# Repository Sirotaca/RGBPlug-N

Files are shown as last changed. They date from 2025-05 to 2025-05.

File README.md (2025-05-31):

# RGBPlug Type N
Compact DE-15 ("VGA") adapter for the SNES/SFC-style AV multi-out. Video timing is unchanged, so a monitor or video processor compatible with 15 kHz RGB is required. The switch toggles between separate H/V sync or composite sync output.

For the NTSC SNES/SFC or PAL GameCube, populate C6-C11 but do not populate R6-R8. For the PAL SNES, populate R6-R8 and bridge the pads of C6-C11.

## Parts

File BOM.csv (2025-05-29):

Reference | Value | Datasheet | Footprint | Qty | DNP
C1 | 1nF | ~ | Capacitor_SMD:C_0805_2012Metric_Pad1.18x1.45mm_HandSolder | 1
C2 | 0.01uF | ~ | Capacitor_SMD:C_0805_2012Metric_Pad1.18x1.45mm_HandSolder | 1
C3 | 10uF | ~ | Capacitor_SMD:C_1206_3216Metric_Pad1.33x1.80mm_HandSolder | 1
C4 | 0.1u | ~ | Capacitor_SMD:C_0805_2012Metric_Pad1.18x1.45mm_HandSolder | 1
C5 | 0.1uF | ~ | Capacitor_SMD:C_0805_2012Metric_Pad1.18x1.45mm_HandSolder | 1
C6,C7,C8 | 0.01u | ~ | Capacitor_SMD:C_0805_2012Metric_Pad1.18x1.45mm_HandSolder | 3
C9,C10,C11 | 470u | ~ | Capacitor_THT:CP_Radial_D6.3mm_P2.50mm | 3
J1 | DB15_Female_HighDensity_MountingHoles | ~ | retro_gaming:L17HTHES4F1C | 1
J2 | AudioJack3 | ~ | Connector_Audio:Jack_3.5mm_CUI_SJ1-3533NG_Horizontal | 1
P1 | SNES_multiAV_plug_PCB |  | retro_gaming:SNES_multiAV_plug_PCB | 1
R1,R2,R6,R7,R8 | 75 | ~ | Resistor_SMD:R_0805_2012Metric_Pad1.20x1.40mm_HandSolder | 5
R3 | 10k | ~ | Resistor_SMD:R_0805_2012Metric_Pad1.20x1.40mm_HandSolder | 1
R4,R5 | 510 | ~ | Resistor_SMD:R_0805_2012Metric_Pad1.20x1.40mm_HandSolder | 2
S1 | JS202011CQN | https://www.ckswitches.com/media/1422/js.pdf | Button_Switch_THT:SW_CuK_JS202011CQN_DPDT_Straight | 1
U1 | LMH1980 | LMH1980 | Package_SO:VSSOP-10_3x3mm_P0.5mm | 1
U2 | 74LVC3G34 | http://www.ti.com/lit/sg/scyt129e/scyt129e.pdf | Package_SO:TSSOP-8_3x3mm_P0.65mm | 1

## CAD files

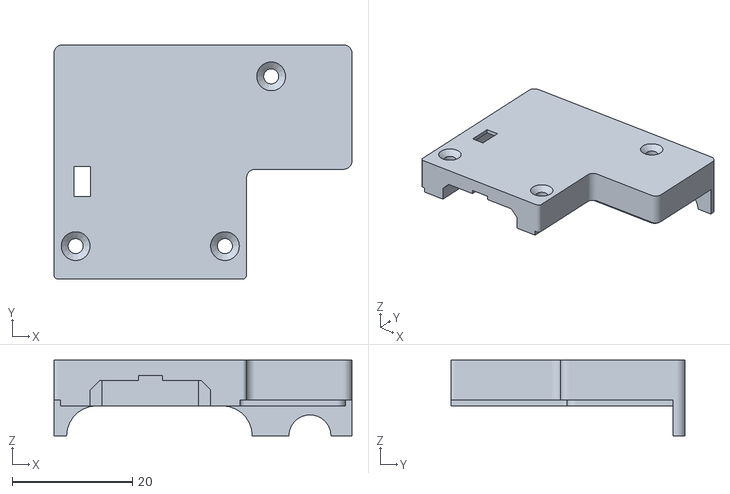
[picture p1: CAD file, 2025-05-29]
Shell/rgbplug_n_top.stl
49.5 x 39.0 x 12.6

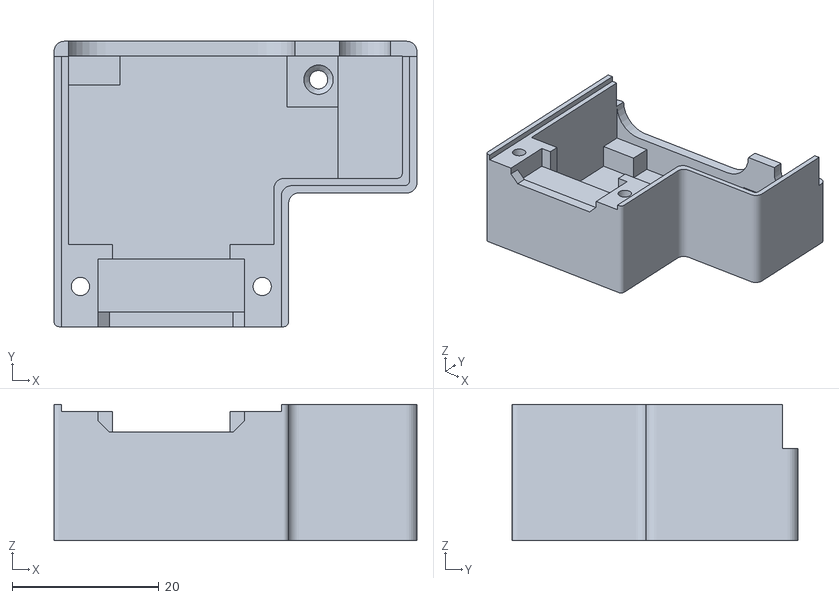
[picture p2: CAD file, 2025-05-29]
Shell/rgbplug_n_bottom.stl
49.5 x 39.0 x 18.6

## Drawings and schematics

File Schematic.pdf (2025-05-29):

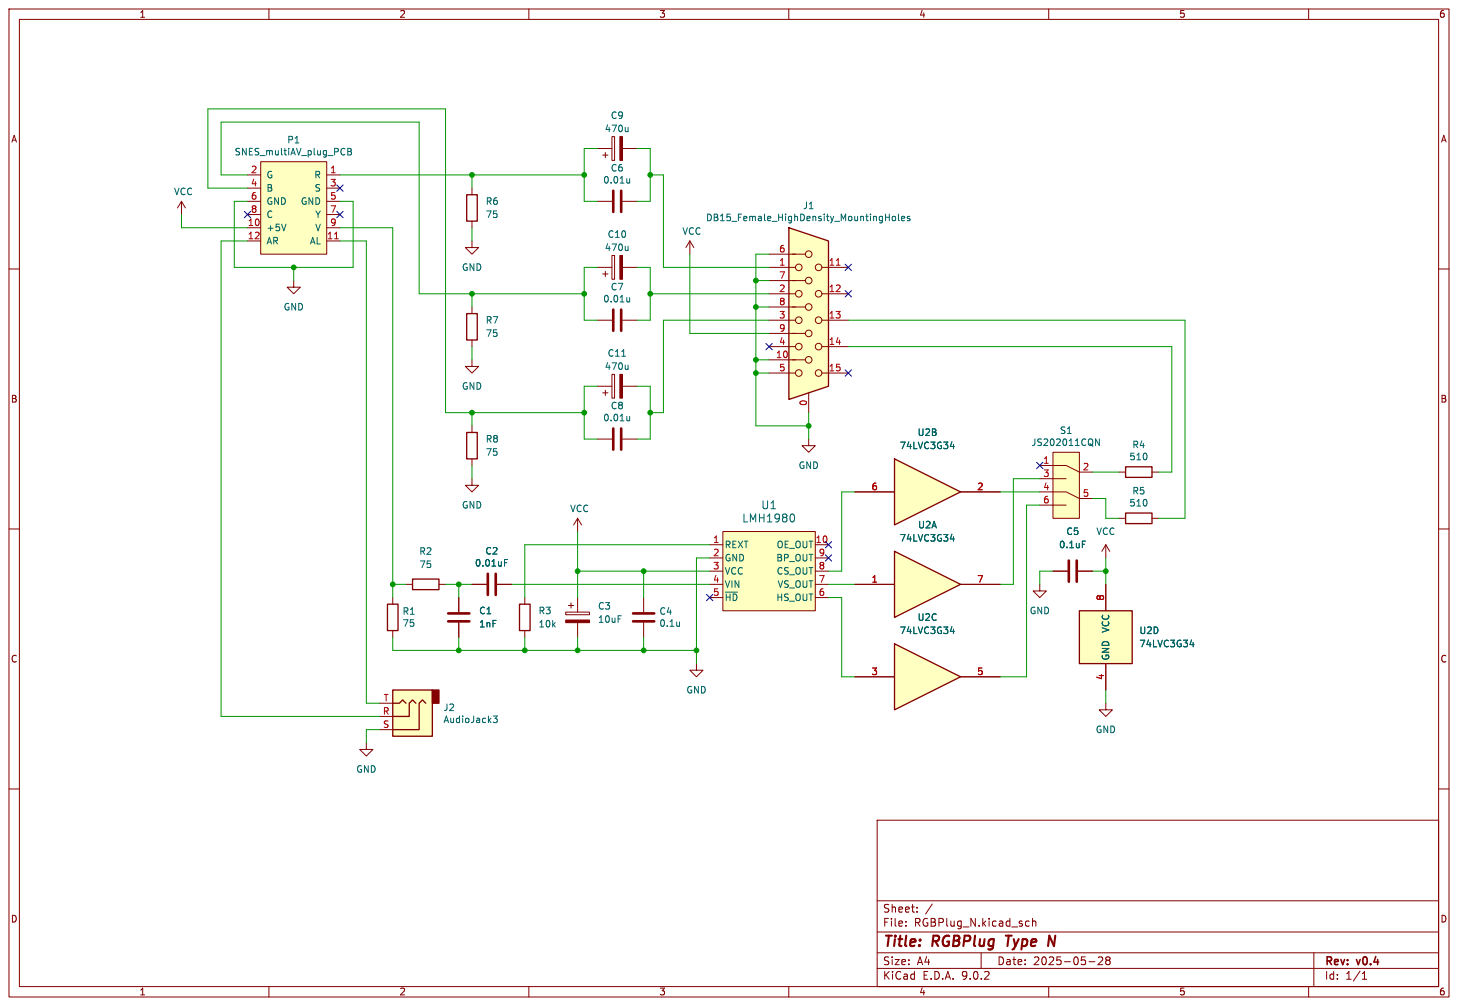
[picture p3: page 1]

Id: 1/1 Title: RGBPlug Type N

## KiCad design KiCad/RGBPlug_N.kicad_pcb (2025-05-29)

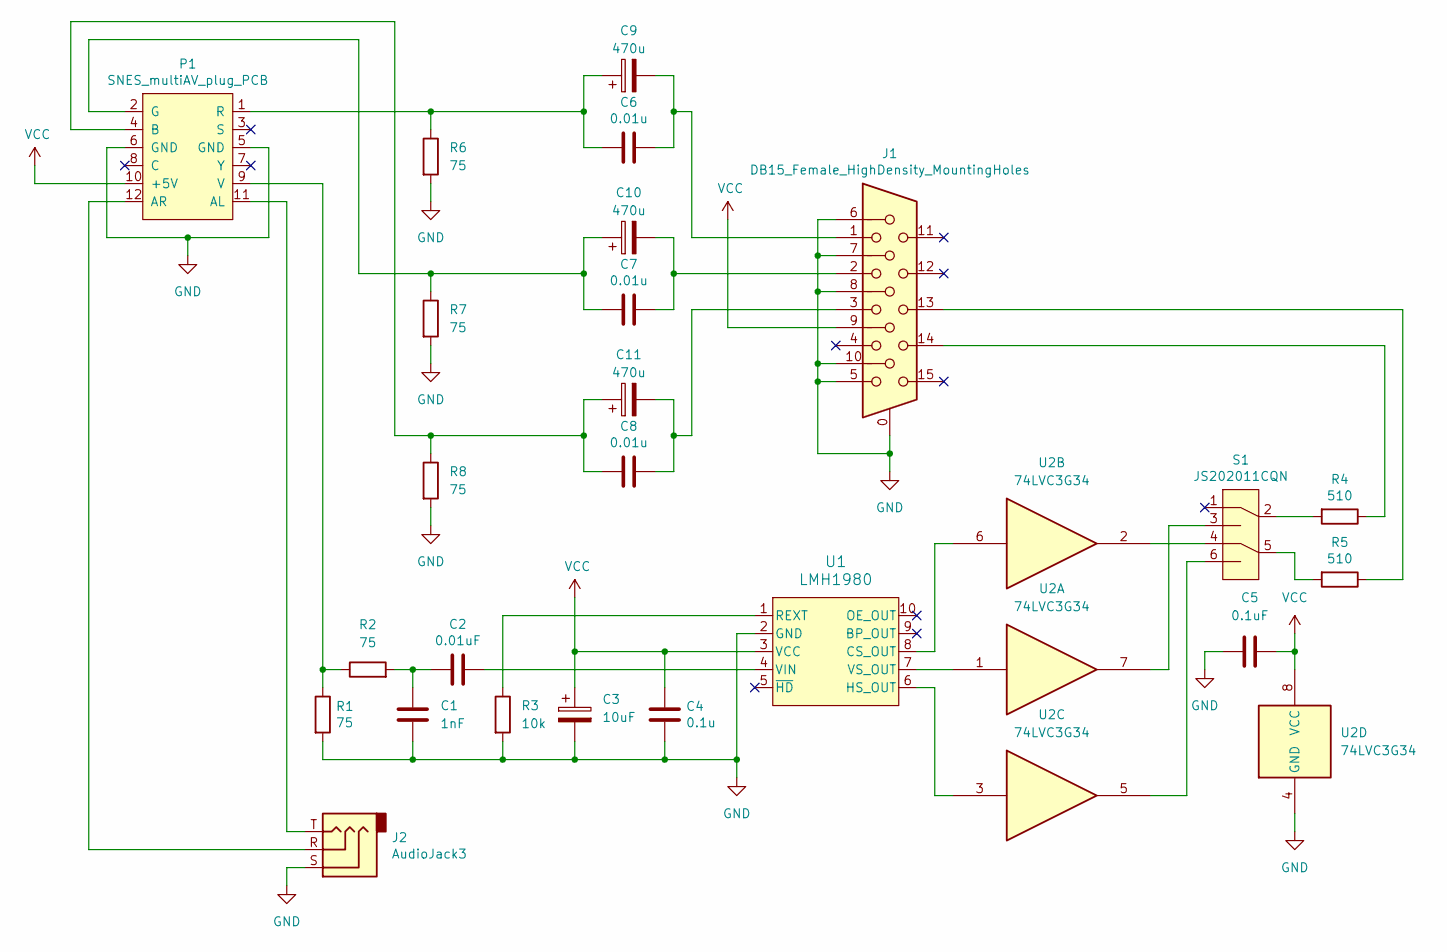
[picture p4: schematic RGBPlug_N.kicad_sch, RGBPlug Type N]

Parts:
C1: 1nF; C_0805_2012Metric_Pad1.18x1.45mm_HandSolder
C2: 0.01uF; C_0805_2012Metric_Pad1.18x1.45mm_HandSolder
C3: 10uF; C_1206_3216Metric_Pad1.33x1.80mm_HandSolder
C4: 0.1u; C_0805_2012Metric_Pad1.18x1.45mm_HandSolder
C5: 0.1uF; C_0805_2012Metric_Pad1.18x1.45mm_HandSolder
C6, C7, C8: 0.01u; C_0805_2012Metric_Pad1.18x1.45mm_HandSolder
C9, C10, C11: 470u; CP_Radial_D6.3mm_P2.50mm
J1: DB15_Female_HighDensity_MountingHoles; L17HTHES4F1C
J2: AudioJack3; Jack_3.5mm_CUI_SJ1-3533NG_Horizontal
P1: SNES_multiAV_plug_PCB
R1, R2, R6, R7, R8: 75; R_0805_2012Metric_Pad1.20x1.40mm_HandSolder
R3: 10k; R_0805_2012Metric_Pad1.20x1.40mm_HandSolder
R4, R5: 510; R_0805_2012Metric_Pad1.20x1.40mm_HandSolder
S1: JS202011CQN; SW_CuK_JS202011CQN_DPDT_Straight
U1: LMH1980; VSSOP-10_3x3mm_P0.5mm
U2: 74LVC3G34; TSSOP-8_3x3mm_P0.65mm

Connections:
GND: C1.2, C3.2, C4.1, C5.1, J1.0, J1.5, J1.6, J1.7, J1.8, J1.10, J2.S, P1.5 (GND), P1.6 (GND), R1.2, R3.2, R6.2, R7.2, R8.2, U1.2 (GND), U2.4 (GND)
unnamed: C1.1, C2.2, R2.2
unnamed: C6.1, C9.2, J1.1
unnamed: C7.1, C10.2, J1.2
unnamed: C8.2, C11.2, J1.3
unnamed: J1.13, R5.1
unnamed: J1.14, R4.1
unnamed: J2.T, P1.11 (AL)
unnamed: J2.R, P1.12 (AR)
unnamed: C8.1, C11.1, P1.4 (B), R8.1
unnamed: C7.2, C10.1, P1.2 (G), R7.1
unnamed: C6.2, C9.1, P1.1 (R), R6.1
unnamed: P1.9 (V), R1.1, R2.1
unnamed: R4.2, S1.2
unnamed: R5.2, S1.5
unnamed: S1.3, U2.7
unnamed: S1.4, U2.2
unnamed: S1.6, U2.5
unnamed: U1.8 (CS_OUT), U2.6
unnamed: U1.6 (HS_OUT), U2.3
unnamed: R3.1, U1.1 (REXT)
unnamed: C2.1, U1.4 (VIN)
unnamed: U1.7 (VS_OUT), U2.1
VCC: C3.1, C4.2, C5.2, J1.9, P1.10 (+5V), U1.3 (VCC), U2.8 (VCC)

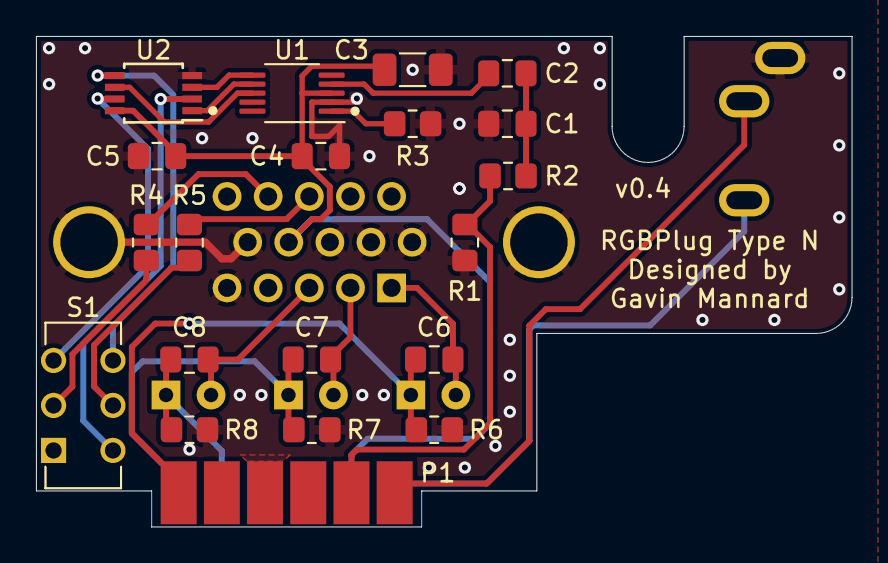
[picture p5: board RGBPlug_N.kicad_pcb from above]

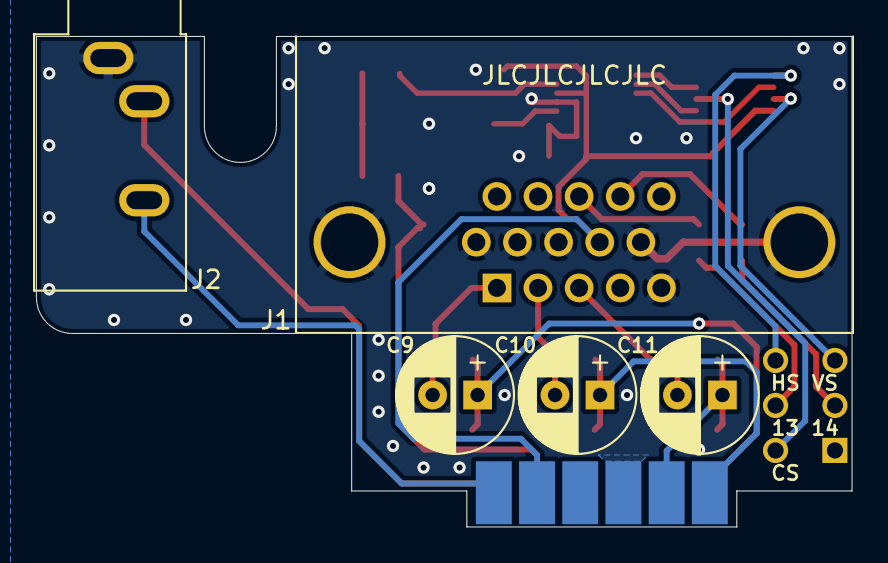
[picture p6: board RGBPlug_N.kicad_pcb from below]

Board: 2 copper layers, 45.3 x 27.2 mm, 25 parts (5 on the bottom side), 24 nets.
